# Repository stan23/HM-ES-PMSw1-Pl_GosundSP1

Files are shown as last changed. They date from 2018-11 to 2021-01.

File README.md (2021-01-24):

# HM-ES-PMSw1-Pl_GosundSP1          

Patrick hat eine [verbesserte Version gemacht](https://github.com/der-pw/HM-ES-PMSw1-Pl_GosundSP1).

Umbau [Gosund SP1 bzw. BliTZWOLF SHP2](https://www.blitzwolf.com/Wifi-Smart-Socket-EU-p-244.html) zu HM-ES-PMSw1-Pl_SP1

Dies basiert auf der hervorragenden Arbeit von [pa-pa](https://github.com/pa-pa/AskSinPP) und [Jérôme](https://github.com/jp112sdl/Beispiel_AskSinPP).

*Achtung*: es kann verschiedene Versionen der Gosund/Blitzwolf-Stecker geben. Diese Platine passt bei folgender Version:

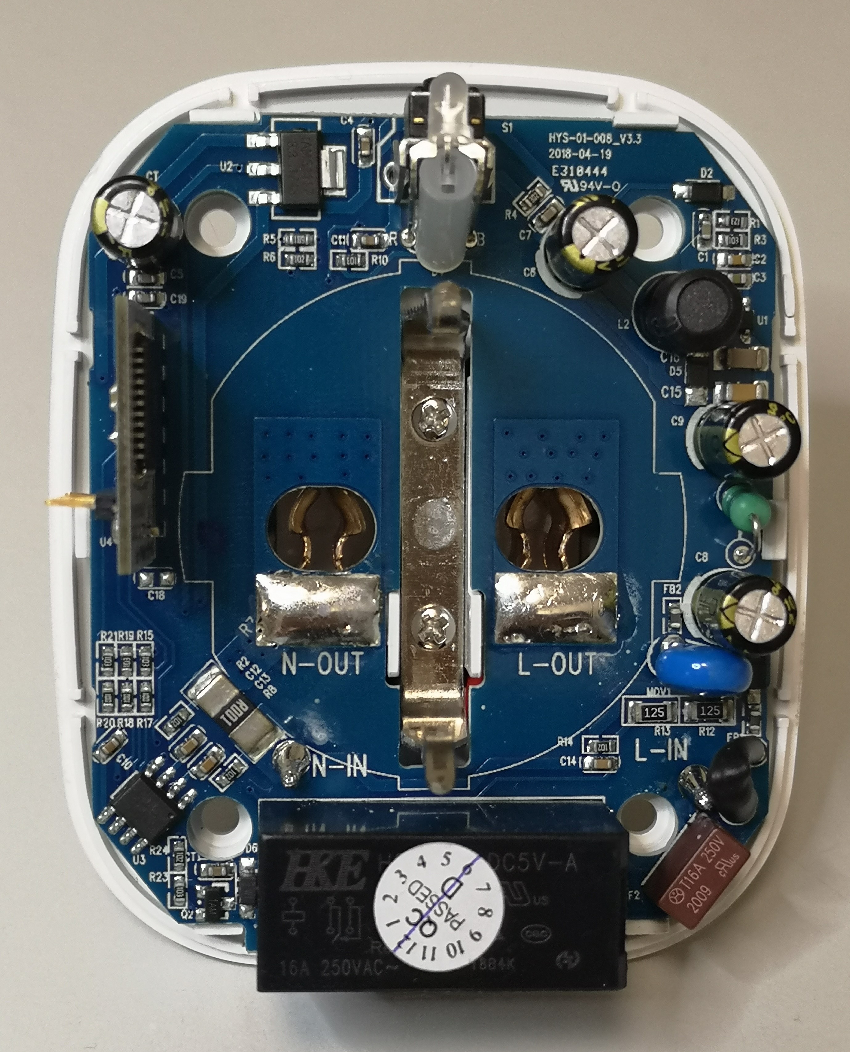
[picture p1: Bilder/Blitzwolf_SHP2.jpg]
Blitzwolf SHP2


# Hardware

### Bauteile

#### Reichelt

[Bestellliste](https://www.reichelt.de/my/1519439)

Bauteil                  | Bestellnummer   | Anzahl | Kommentar
------------------------ | --------------- | ------ | ---------
C1                       | X5R-G0603 10/6  |   1    | -
C2 .. C6                 | X7R-G0603 100N  |   5    | -
R1                       | RND 0603 1 10K  |   1    | -
R2                       | RND 0603 1 1,0M |   1    | -
U1                       | ATMEGA 644PA-AU |   1    | -
Y1                       | CSTCE 8,00      |   1    | -
Verbinder zu U2          | MPE 156-1-032   |   1    | muss per Hand umgebogen werden
Verbinder zu U2          | SL 1X20G 2,00   |   1    | optional, hilfreich zum Anschließen des ISP

#### Sonstiges

Bauteil | Bestellnummer            | Anzahl | Kommentar
------- | ------------------------ | ------ | ---------
U2      | CC1101 Funkmodul 868 MHz |   1    | z.B. [eBay](https://www.ebay.de/itm/272455136087)

~8,3 cm Draht als Antenne

### Programmieradapter
- 1x ISP (z.B. [diesen hier](https://www.diamex.de/dxshop/USB-ISP-Programmer-fuer-Atmel-AVR-Rev2))

# Software

### Fuses
Ext:  0xFF
High: 0xD2
Low:  0xFF (für den internen Takt: 0xE2)

`C:\Program Files (x86)\Arduino\hardware\tools\avr\bin> .\avrdude -C ..\etc\avrdude.conf -p m644p -P com7 -c stk500 -U lfuse:w:0xFF:m -U hfuse:w:0xD2:m -U efuse:w:0xFF:m`

### Firmware

Projektverzeichnis: [HM-ES-PMSw1-Pl_GosundSP1](https://github.com/jp112sdl/Beispiel_AskSinPP/tree/master/examples/HM-ES-PMSw1-Pl_GosundSP1)

Benötigt werden die Bibliotheken [AskSinPP](https://github.com/pa-pa/AskSinPP) aus dem master-Branch, sowie die [HLW8012](https://github.com/xoseperez/hlw8012), die [MightyCore](https://github.com/MCUdude/MightyCore), die [EnableInterrupt](https://github.com/GreyGnome/EnableInterrupt) und [Low-Power](https://github.com/rocketscream/Low-Power).

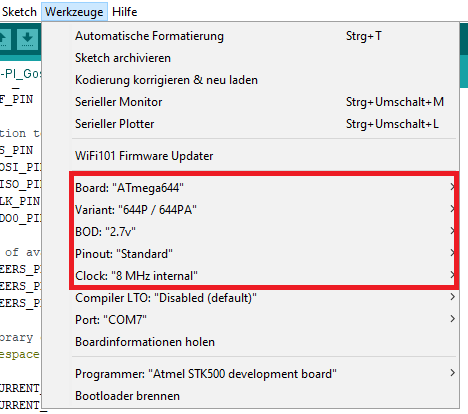
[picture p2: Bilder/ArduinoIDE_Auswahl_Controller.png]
Einstellungen IDE


# Bauanleitung

Zuerst den ATmega auflöten, die Markierung (kleiner Punkt) muss zur Beschriftung U1 zeigen.
Danach die Kondensatoren und den Widerstand auflöten.

Mit einem Multimeter messen ob kein Kurzschluss zwischen VCC und GND besteht (mehrere 10 K Widerstand sind okay).

Den ISP Programmieradapter an die Lötaugen des CC1101 anschließen. Ein Adapterkabel vom 6-poligen ISP-Adapter auf eine 2 mm-Stiftleiste wird empfohlen :)

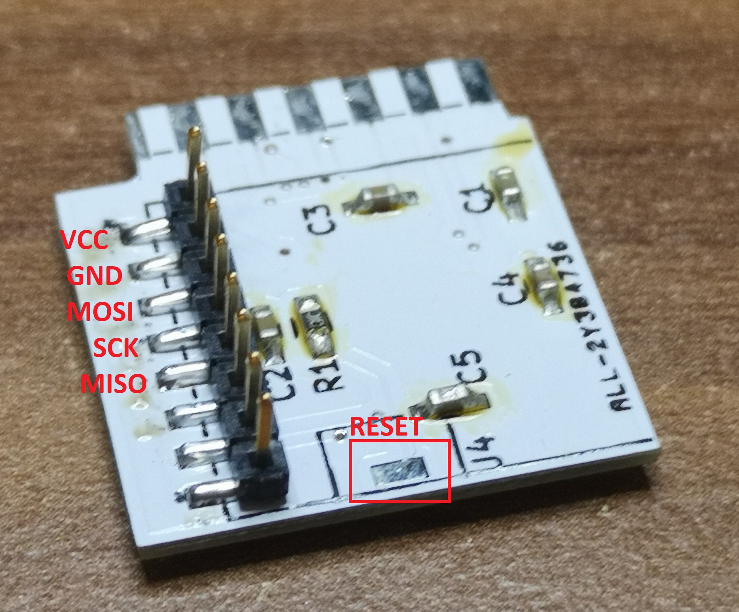
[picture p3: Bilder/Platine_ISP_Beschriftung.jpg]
ISP Anschluss


Pin am ISP-Kabel | Bedeutung
---------------- | ----------
1                | MISO
2                | VCC
3                | SCK
4                | MOSI
5                | Reset
6                | GND

Anschließend kann das Funkmodul auf der Rückseite aufgelötet werden. Dabei gibt es verschiedene Möglichkeiten:
- mit Stift- und Buchsenleiste (abnehmbar)
- mit Stiftleiste

An den Antennenanschluss muss noch das 8,3 cm Drahtstück angelötet werden.

Mit einem FTDI USB-seriell-Adapter an den Lötpunkten RX, TX, 3.3 V und GND und mit einem Terminalprogramm kann man die Ausgabe beobachten. Es sollten schon *Ignore...*-Meldungen empfangen und angezeigt werden.

Als nächstes muss das überflüssige WLAN-Modul aus dem Gosund/Blitzwolf-Stecker ausgelötet und die neue Platine eingelötet werden. Der Antennendraht muss mit Heißkleber im Gehäuse befestigt werden, so dass er möglichst weit von 230 V entfernt ist!

Nach dem Zusammenbau kann der Anlernvorgang durch langes Drücken der einzigen Taste gestartet werden. Die Anlernprozedur wird durch langsames Blinken der blauen WLAN-LED angezeigt, der Erfolg durch schnelles Blinken.

# Kalibrierung

TBD

# Bilder

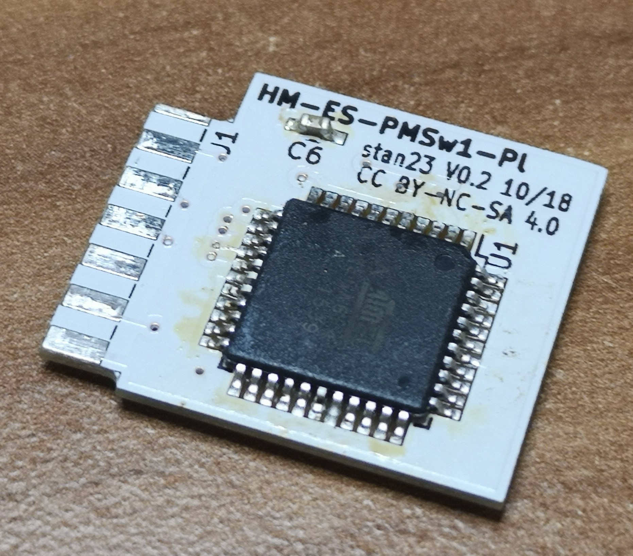
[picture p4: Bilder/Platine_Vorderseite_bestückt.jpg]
ATmega

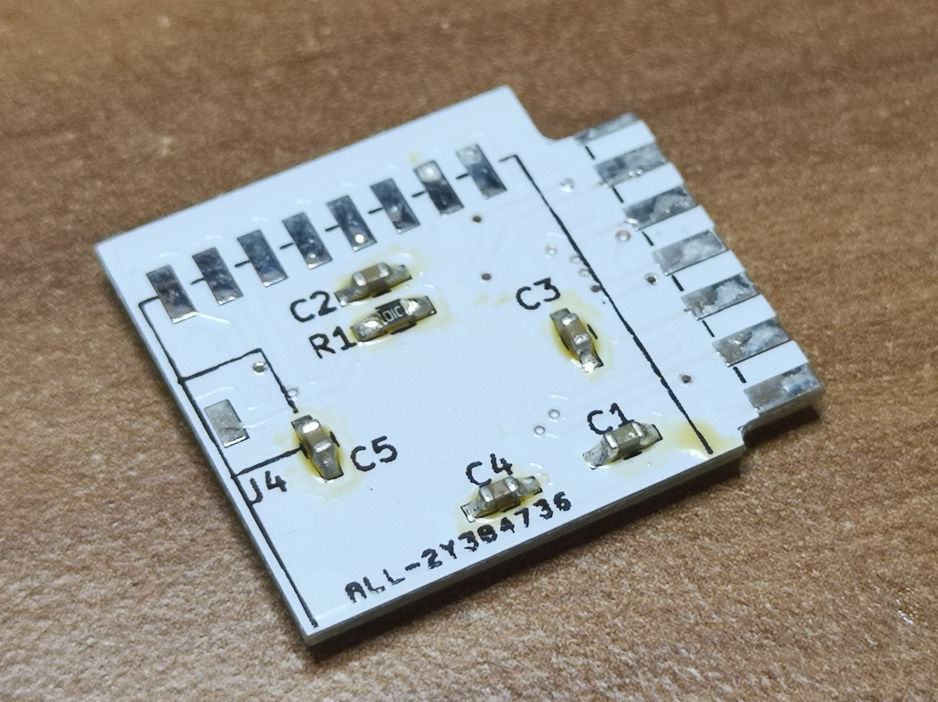
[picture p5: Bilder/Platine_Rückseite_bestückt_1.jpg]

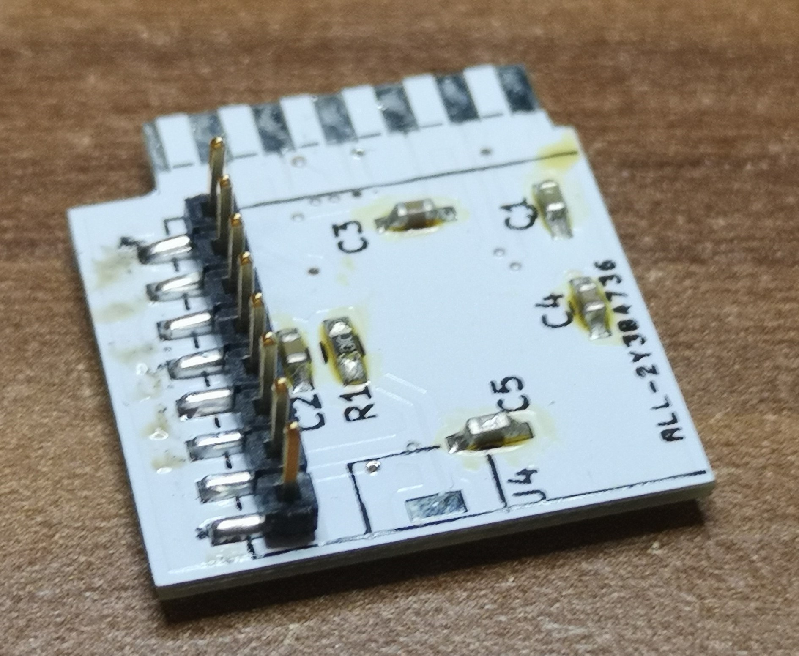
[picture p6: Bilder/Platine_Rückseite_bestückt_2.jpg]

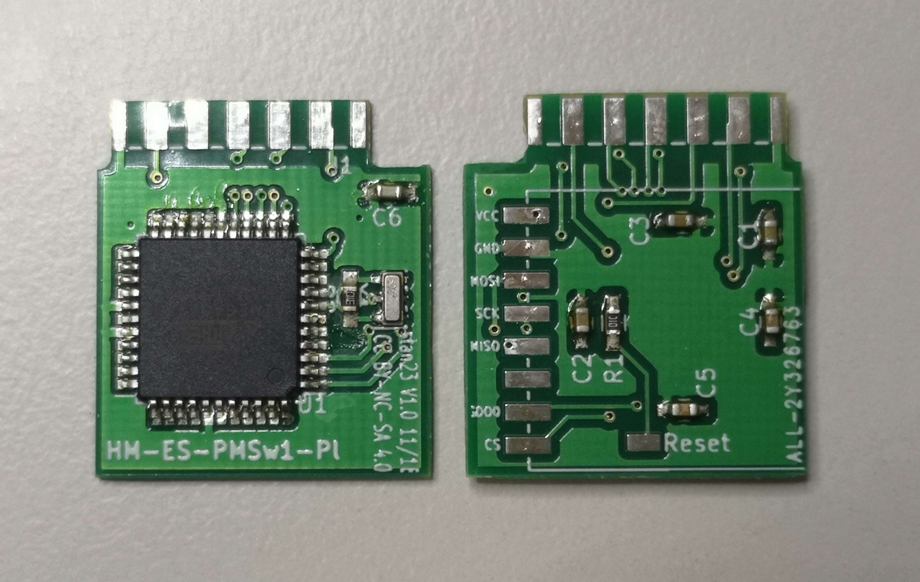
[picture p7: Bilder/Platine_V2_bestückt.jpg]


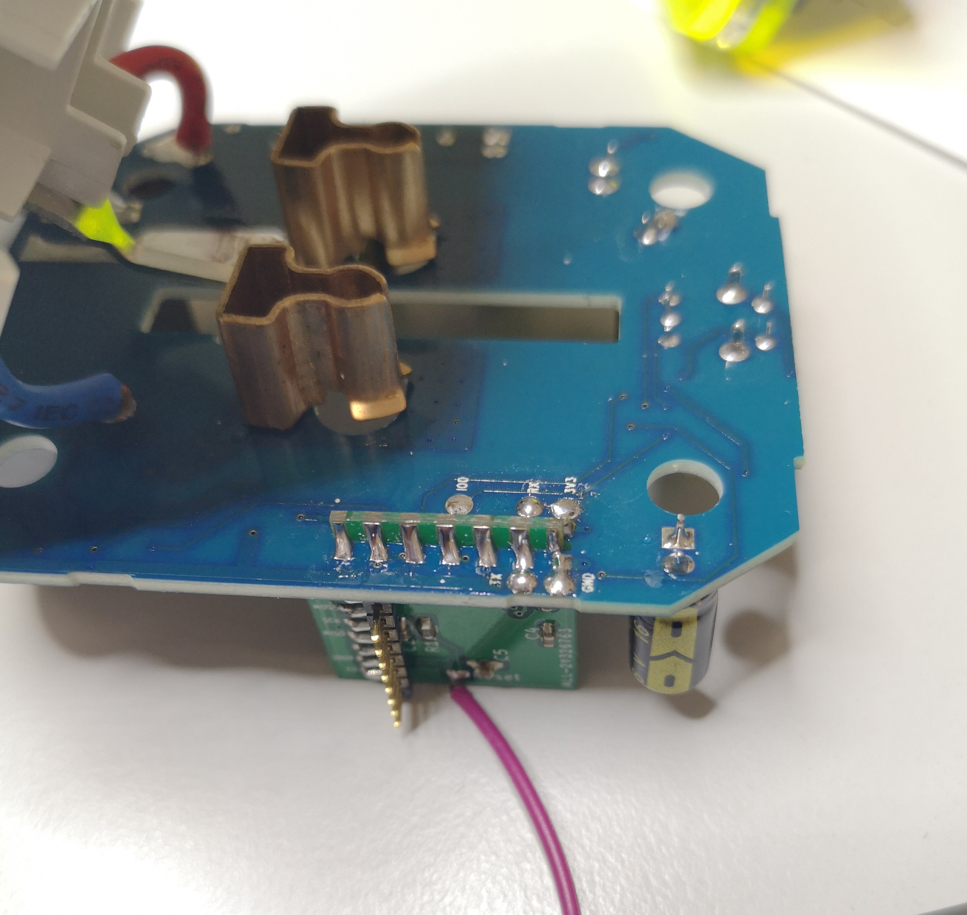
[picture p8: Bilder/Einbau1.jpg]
Einbau

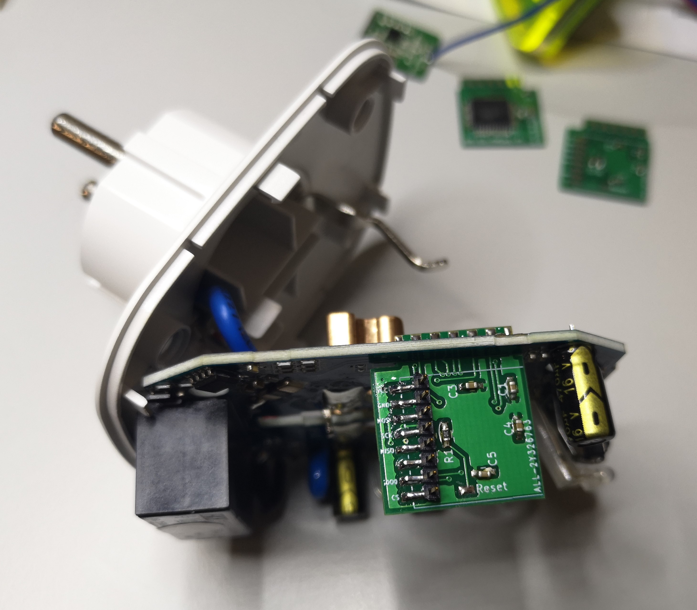
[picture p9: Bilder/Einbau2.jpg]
Einbau

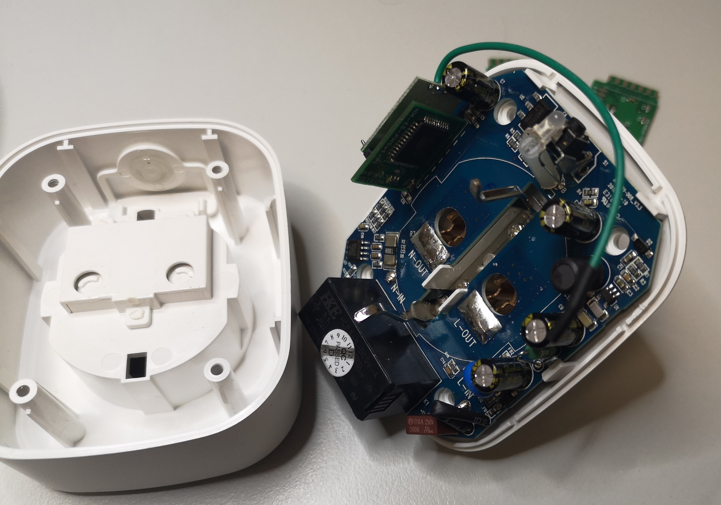
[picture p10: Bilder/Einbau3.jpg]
Einbau

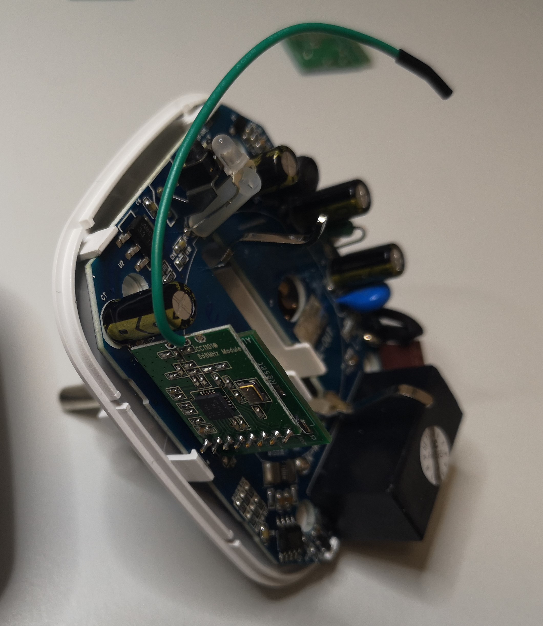
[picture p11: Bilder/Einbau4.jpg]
Einbau




Dieses Werk ist lizenziert unter einer [Creative Commons Namensnennung - Nicht-kommerziell - Weitergabe unter gleichen Bedingungen 4.0 International Lizenz](http://creativecommons.org/licenses/by-nc-sa/4.0/).

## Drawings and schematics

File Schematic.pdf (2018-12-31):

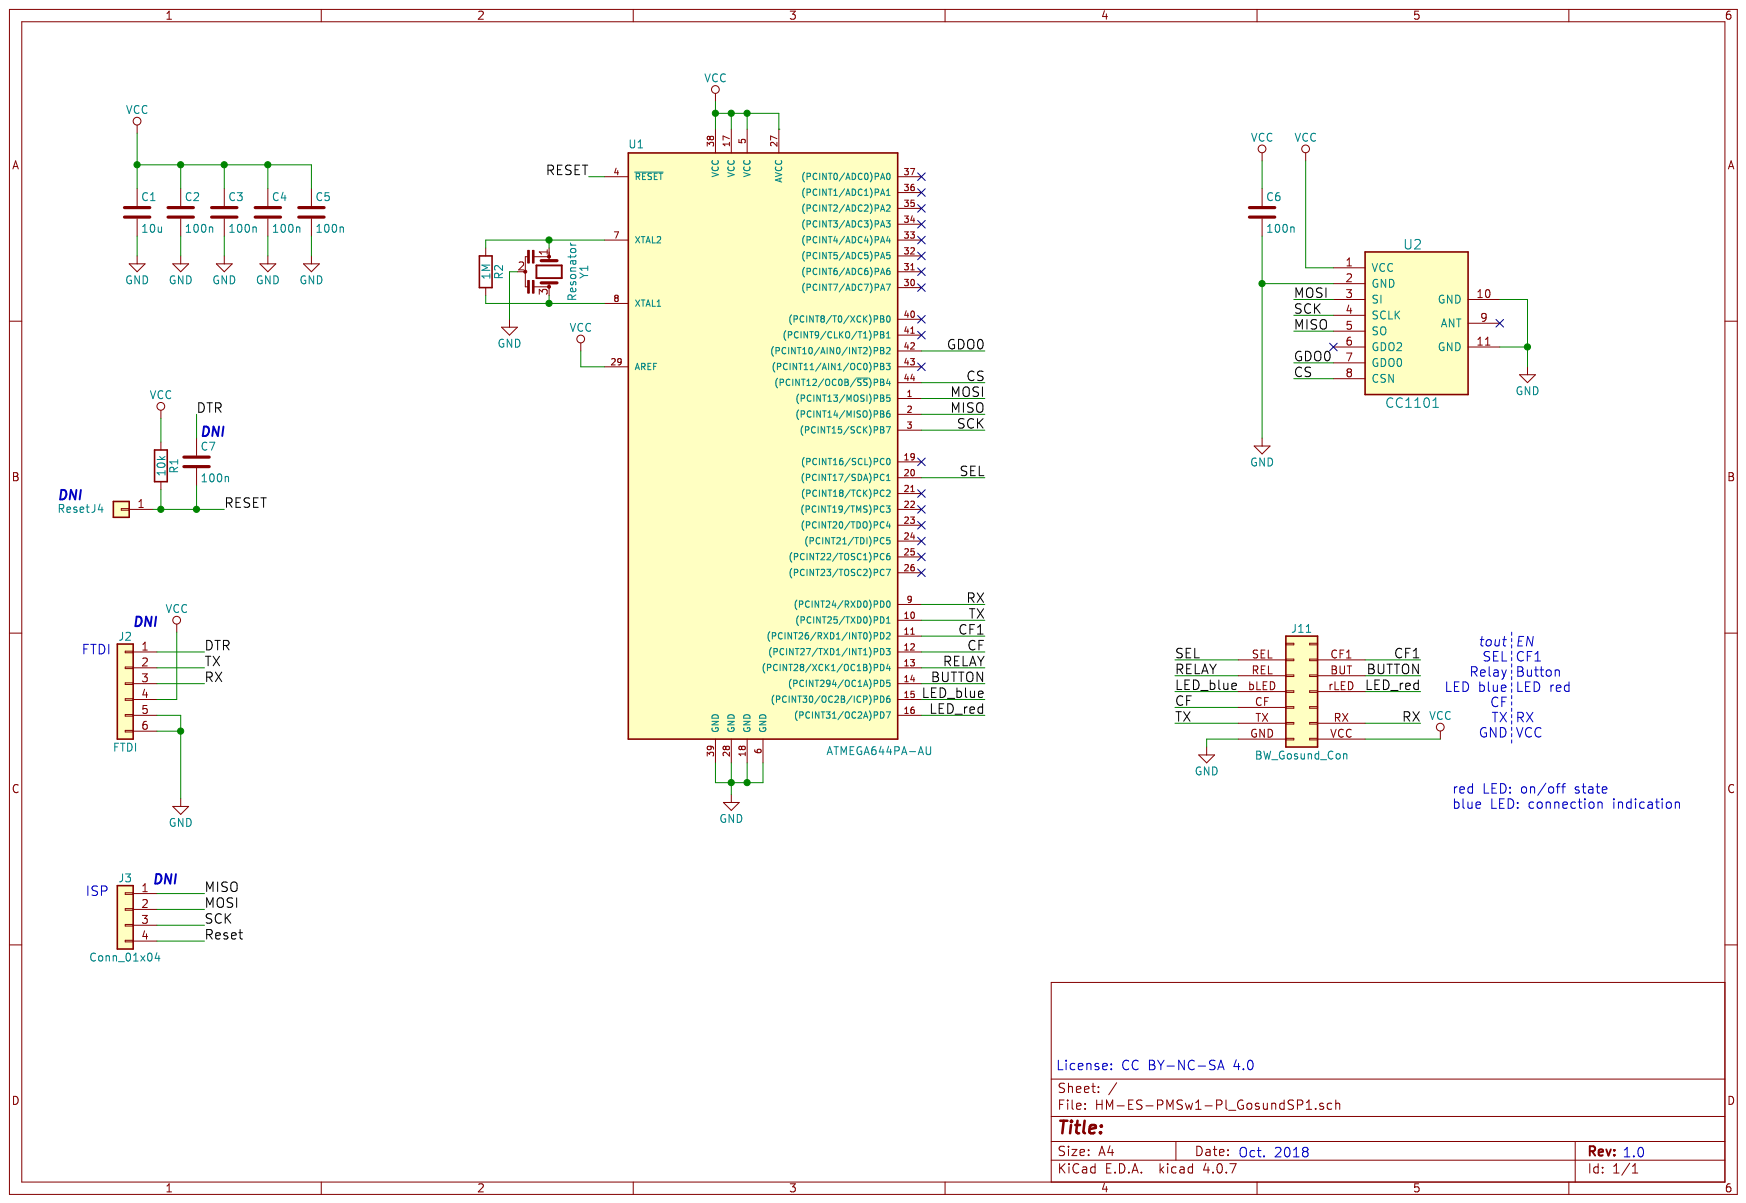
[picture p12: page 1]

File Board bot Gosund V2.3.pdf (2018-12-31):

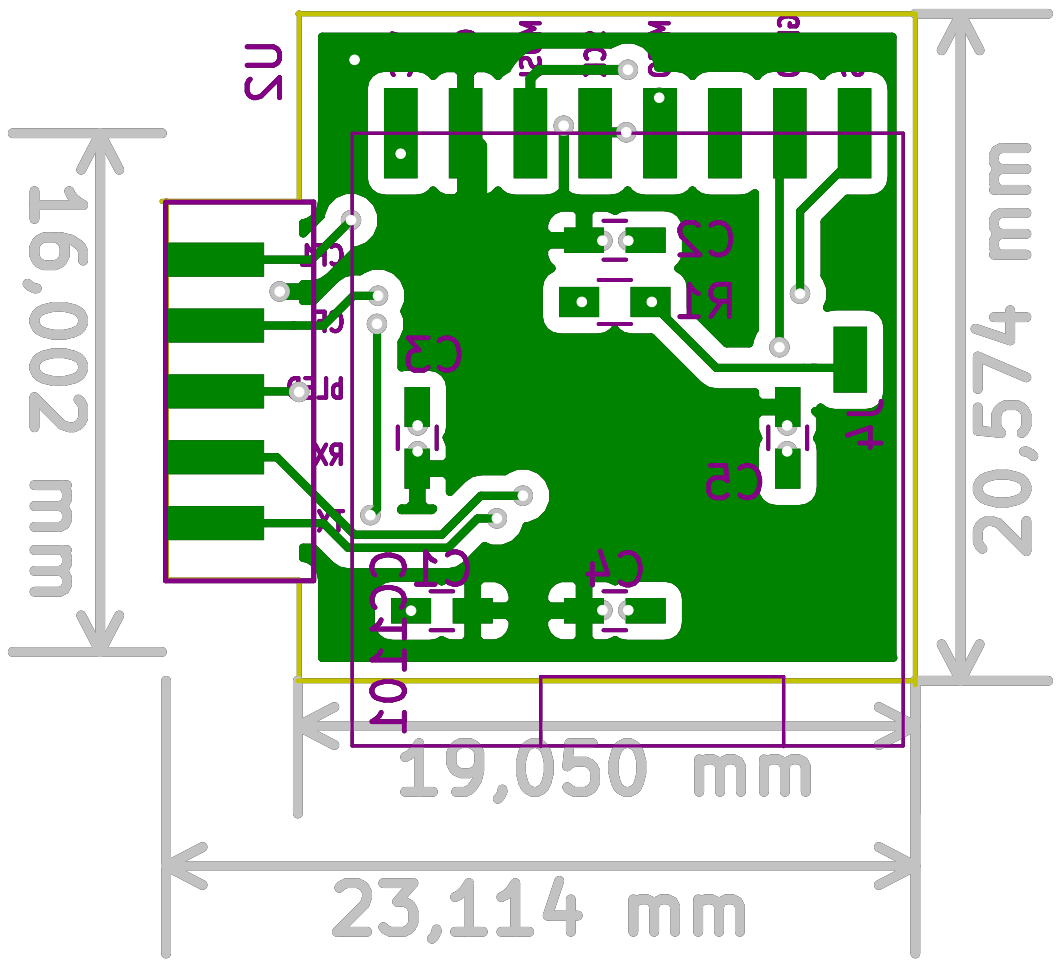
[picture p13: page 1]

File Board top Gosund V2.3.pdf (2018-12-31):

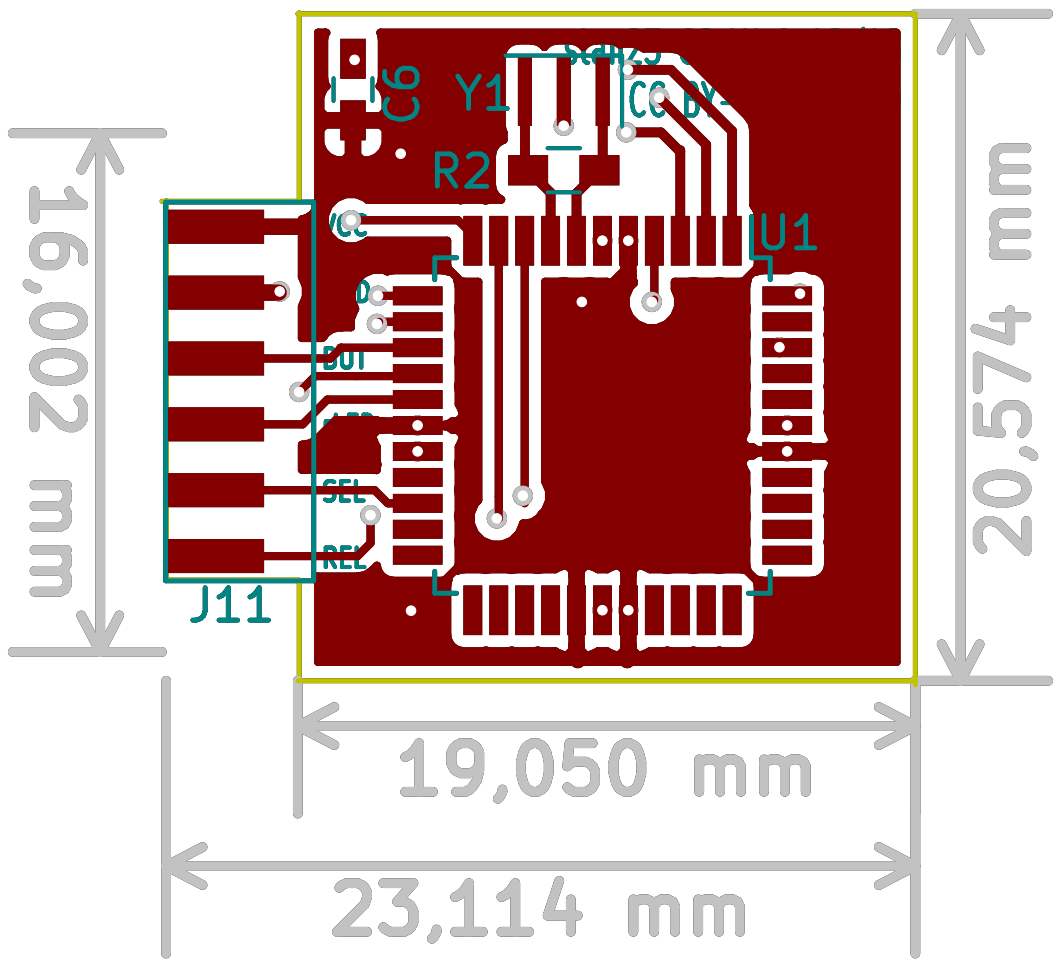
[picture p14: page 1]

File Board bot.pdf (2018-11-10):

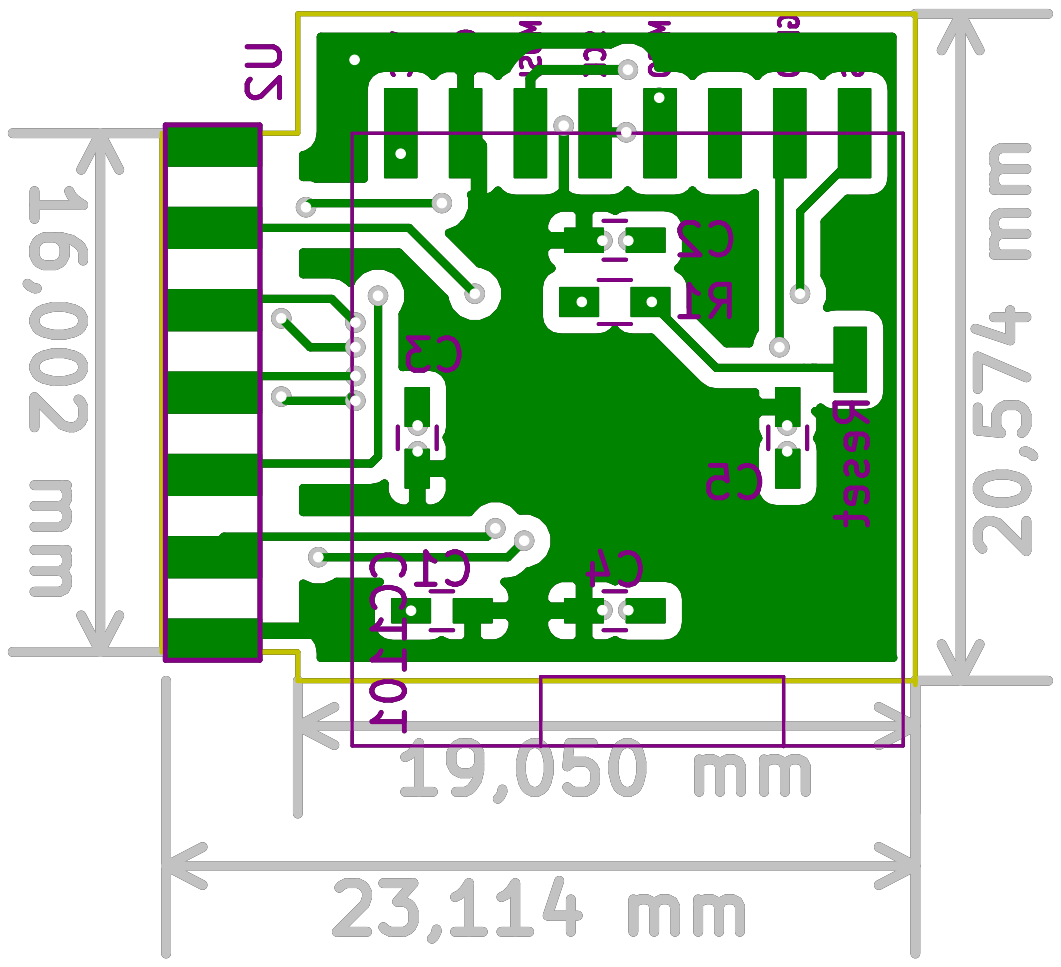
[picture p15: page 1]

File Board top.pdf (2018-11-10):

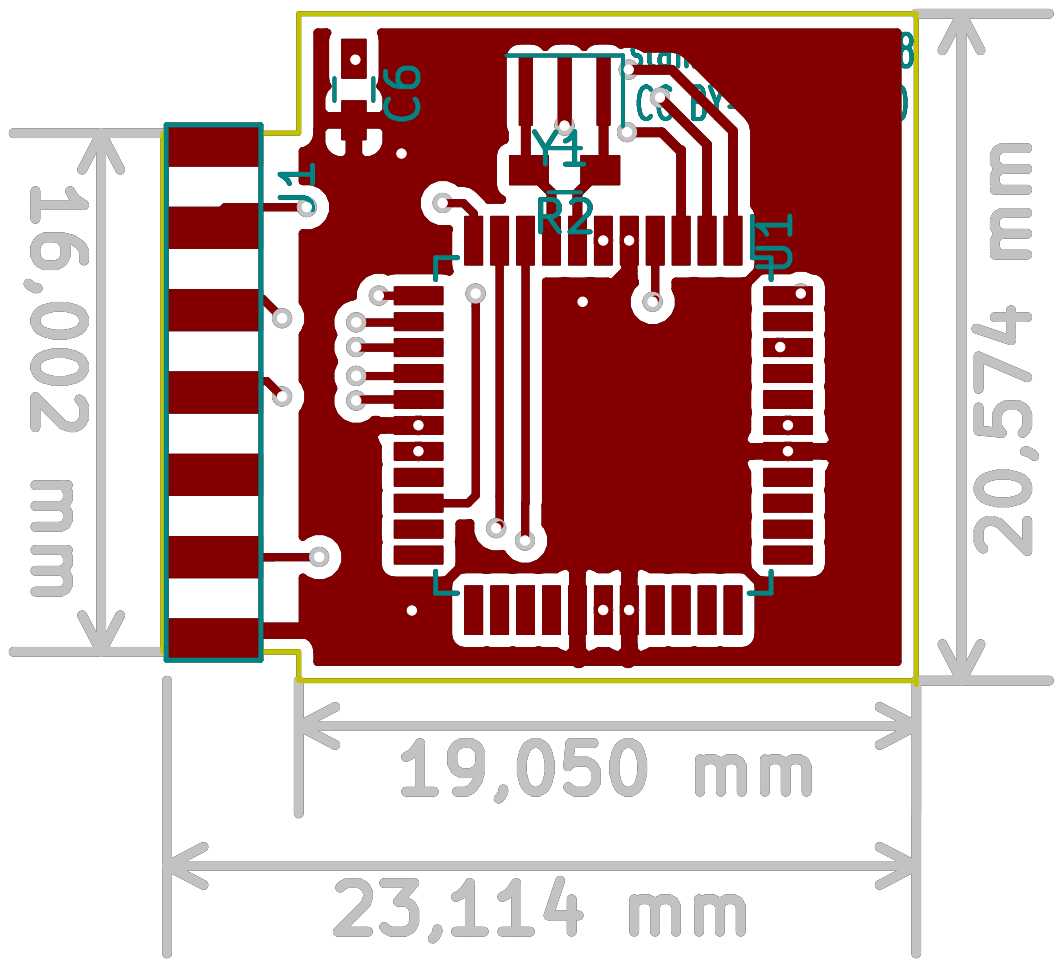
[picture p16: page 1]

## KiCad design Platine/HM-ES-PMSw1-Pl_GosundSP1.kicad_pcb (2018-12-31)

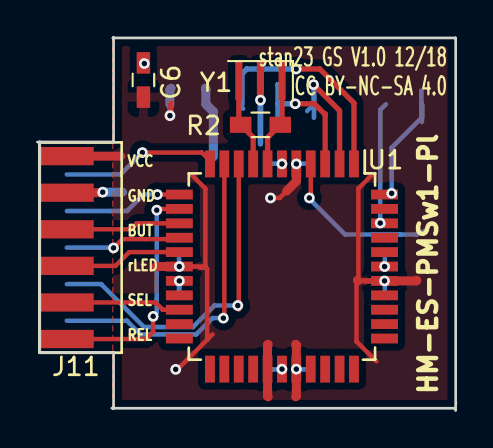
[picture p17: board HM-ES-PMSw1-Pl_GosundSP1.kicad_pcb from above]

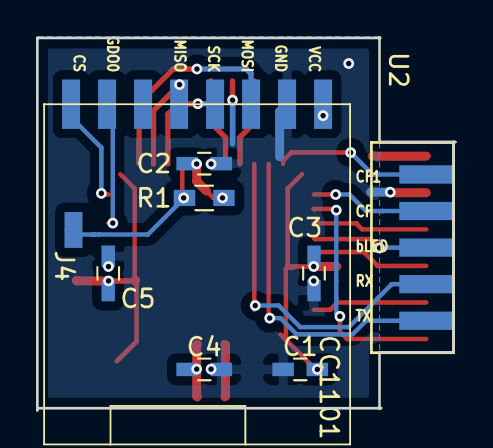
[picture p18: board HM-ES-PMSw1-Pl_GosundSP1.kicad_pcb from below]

Board: 2 copper layers, 23.2 x 20.6 mm, 13 parts (8 on the bottom side), 19 nets.

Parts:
C1: 10u; C_0603_HandSoldering
C2, C3, C4, C5, C6: 100n; C_0603_HandSoldering
J4: Reset; Testpad
J11: BW_Gosund_Con; Gosund_SP1-C_V2.3
R1: 10k; R_0603_HandSoldering
R2: 1M; R_0603_HandSoldering
U1: ATMEGA644PA-AU; TQFP-44_10x10mm_Pitch0.8mm
U2: CC1101; CC1101_SMD
Y1: Resonator; Resonator_SMD_muRata_TPSKA-3pin_7.9x3.8mm_HandSoldering

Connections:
/BUTTON: J11.BUT, U1.14
/CF: J11.CF, U1.12
/CF1: J11.CF1, U1.11
/CS: U1.44, U2.8
/GDO0: U1.42, U2.7
/LED_blue: J11.bLED, U1.15
/LED_red: J11.rLED, U1.16
/MISO: U1.2, U2.5
/MOSI: U1.1, U2.3
/RELAY: J11.REL, U1.13
/RESET: J4.1, R1.2, U1.4
/RX: J11.RX, U1.9
/SCK: U1.3, U2.4
/SEL: J11.SEL, U1.20
/TX: J11.TX, U1.10
GND: C1.2, C2.2, C3.2, C4.2, C5.2, C6.2, J11.GND, U1.6, U1.18, U1.28, U1.39, U2.2, Y1.2
unnamed: R2.1, U1.7, Y1.1
unnamed: R2.2, U1.8, Y1.3
VCC: C1.1, C2.1, C3.1, C4.1, C5.1, C6.1, J11.VCC, R1.1, U1.5, U1.17, U1.27, U1.29, U1.38, U2.1

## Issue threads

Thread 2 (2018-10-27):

Label connector's pins

stan23, 2018-10-27:

stan23, 2018-11-10:
fixed in V1.0

Closed 2018-11-10.

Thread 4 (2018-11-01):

Evaluate external clock

stan23, 2018-11-01:
The current, voltage, power measurements are quite inaccurate.

Maybe it is advised to mount an external clock generator and don't use the internal oscillator?

pa-pa, 2018-11-02:
I also think an external crystal will improve the measured values.

stan23, 2018-11-02:
I'm wondering whether the 0.5% of https://www.reichelt.de/smd-resonator-8-00-mhz-groesse-3-2x1-3x0-9mm-cstce-8-00-p89701.html are sufficient.

stan23, 2018-11-02:
Wenn ich bei Reichelt schaue, finde ich folgendes:

Resonator:
[CSTCE 8,00](https://www.reichelt.de/smd-resonator-8-00-mhz-groesse-3-2x1-3x0-9mm-cstce-8-00-p89701.html)
Maße: 3,2x1,3x0,9mm
Frequenztoleranz: ± 0,5 %
Preis: 0,31 Euro

Quarz:
[8,000000-MQ](https://www.reichelt.de/keramik-smd-quarz-5x7x1-2mm-8-0-mhz-8-000000-mq-p84989.html?)
Maße: 5,0 x 7,0 x 1,2 mm
Frequenztoleranz: ± 30 ppm
Preis: 0,83 Euro
Benötigt zwei zusätzliche Kondensatoren mit 22 pF!

Quarzoszillator:
[XO32 8,00000](https://www.reichelt.de/quarzoszillator-keramik-smd-xo32-8-0-mhz-xo32-8-00000-p101055.html?)
Maße: 2,5 x 3,2 x 0,95 mm
Frequenzstabiliät: +-50ppm
Preis: 1,40 Euro

Ich denke der Quarz scheidet wegen der Größe aus.

pa-pa, 2018-11-02:
Ich denke der "einfache" Resonator ist ausreichend, da er schon um Faktor 5-10 besser ist als der interne. Außerdem ist er nicht so Temperatur abhängig.

jp112sdl, 2018-11-03:
Bei meinem Testaufbau mit internem Takt erhalte ich jetzt gleichmäßig saubere Werte.
Eine angeschlossene ohmsche Last (Glühlampe) von 40W wird bei mir fast immer mit 40W erfasst, in seltenen Fällen mal mit 39W oder 41W. Ich denke mal, besser wird es nicht gehen.

Ein ext. Takt kann m.M. nach aber nicht schaden.
Gerade beim seriellen Debug sieht man doch recht häufig Schrottzeichen.

Werde heute mal mit einem Reso vom Pro Mini testen (wenn ich es löttechnisch auf die Reihe bekomme).

jp112sdl, 2018-11-03:
1x schmunzeln 😄 So sieht mein Testaufbau aus:

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

Habe die Fuse auf ext 8MHz gestellt (low fuse = 0xff).
Die seriellen Ausgaben kommen nun fehlerfrei.
An der Messung hat sich nichts geändert - aber die war bei mir ja auch schon vorher top.

Wie man den Reso mit nem Lötkolben auf die Platine bekommt, weiß ich nicht.
Dafür fehlt mir die SMD-Löterfahrung. Seitlich ist nur minimal Lötfläche vorhanden.

stan23, 2018-11-03:
Sehr schick :smile:
Wie hast du den Resonator denn runter bekommen? Ich denke wenn die Pads etwas länger sind geht das schon mit dem Lötkolben.
Diese Platine ist übrigens mit Heißluft gelötet, die no-clean-Paste hinterlässt diese ekligen gelben harten Rückstände...

jp112sdl, 2018-11-03:
> Wie hast du den Resonator denn runter bekommen?

Hab ihn in einem dicken Tropfen Zinn getränkt, dann ist er von selbst von der Platine gerutscht. 🤓

> die no-clean-Paste hinterlässt diese ekligen gelben harten Rückstände...

Function first! 👍 Sieht man ja nicht. Ist im geschlossenen Gehäuse. _(sollte zumindest so sein ;))_

stan23, 2018-11-10:
fixed in V1.0

Closed 2018-11-10.

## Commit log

2018-10-10 add schematic and KiCad project
    [HM-ES-PMSw1-Pl_SP1.sch, Mapping Ausgangsfrequenz.xlsx]
2018-10-11 rename KiCad files to reflect new repo name
    [HM-ES-PMSw1-Pl_GosundSP1.sch]
2018-10-12 update schematic
    [HM-ES-PMSw1-Pl_GosundSP1.sch]
2018-10-19 oard V0.1 routing complete
    [HM-ES-PMSw1-Pl_GosundSP1.kicad_pcb, HM-ES-PMSw1-Pl_GosundSP1.sch]
2018-10-22 fix wrong Paste layer in connetor
    [HM-ES-PMSw1-Pl_GosundSP1.kicad_pcb]
2018-11-04 add resonator for better clock
    e.g. CSTCE8M00G55-R0, available at Reichelt (CSTCE 8,00)
    [HM-ES-PMSw1-Pl_GosundSP1.kicad_pcb, HM-ES-PMSw1-Pl_GosundSP1.sch]
2018-11-10 finalize V1.0
    fix #1, #2, #4
    [HM-ES-PMSw1-Pl_GosundSP1.kicad_pcb, HM-ES-PMSw1-Pl_GosundSP1.sch]
2018-11-10 Update README.md
    add resonator and 1M resistor to BOM
2018-12-21 Support for Gosund SP1 V2.3 (new WiFi module)
    [HM-ES-PMSw1-Pl_BW_SHP1.kicad_pcb, HM-ES-PMSw1-Pl_GosundSP1.sch]
2018-12-31 fix wrong blue LED and button for Gosund SP1 V2.3
    [HM-ES-PMSw1-Pl_GosundSP1.kicad_pcb]
2021-01-24 link to der-pw's fork

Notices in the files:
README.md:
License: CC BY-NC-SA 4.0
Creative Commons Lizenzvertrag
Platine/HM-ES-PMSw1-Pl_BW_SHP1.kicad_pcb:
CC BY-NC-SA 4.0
